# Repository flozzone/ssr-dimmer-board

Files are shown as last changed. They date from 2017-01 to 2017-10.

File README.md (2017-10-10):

# ssr-dimmer-board

Rebuild of https://github.com/fleshgordo/diskohedron using recent 
SSRs with source code for Arduino microcontroller.

## Hardware

* Schematic: https://github.com/flozzone/ssr-dimmer-board/blob/master/hw/schematic.pdf
* Layout: https://github.com/flozzone/ssr-dimmer-board/blob/master/hw/layout.pdf

## Building

    # prepare build framework
    cd src
    ./configure
    
    # building arduino v3.1 firmware
    cd bin-firmware
    make
    cd ..

    # building client library
    cd bin-client
    make
    cd ..
    
## Uploading

After having run through the building process you can upload the firmware
to the arduino. Be sure to attach the arduino with an USB cable to the 
workstation (It should be recognized as /dev/ttyUSB0).

    cd src/bin-firmware
    make upload
    
## Pin-Mapping

| Pin name 	| Description 	| Type (AVR side) 	| Arduino Pin 	| AVR Pin 	|
|---	|---	|---	|---	|---	|
| ZC 	| Zero cross 	| INPUT 	| digital pin 2 	| PD2 	|
| CH1 	| Channel1 control 	| OUTPUT 	| digital pin 4 	| PD4 	|
| CH2 	| Channel2 control 	| OUTPUT 	| digital pin 5 	| PD5 	|
| CH3 	| Channel3 control 	| OUTPUT 	| digital pin 6 	| PD6 	|
| CH4 	| Channel4 control 	| OUTPUT 	| digital pin 7 	| PD7 	|
| CH5 	| Channel5 control 	| OUTPUT 	| digital pin 8 	| PB0 	|
| GND 	| Ground 	| POWER 	| GND 	| GND 	|

## Serial Protocol

The serial protocol consists of one single 5 byte message, which is described
in the following struct message. 

For the value argument of the message, currently only values between 0 and 16
are allowed.

    struct message {
      byte magic1 = 0xF6;
      byte magic2 = 0x6F;
      enum e_fire_type fire_type;
      enum e_channels channel_nr;
      byte value;
    };

    enum e_fire_type {
        NO_FIRE,
        PHASE_TRAILING_EDGE,
        PHASE_LEADING_EDGE,
        FULL_WAVE_BURST,
        HALF_WAVE_BURST
    };

    enum e_channels {
        CHANNEL1 = 0,
        CHANNEL2,
        CHANNEL3,
        CHANNEL4,
        CHANNEL5
    };

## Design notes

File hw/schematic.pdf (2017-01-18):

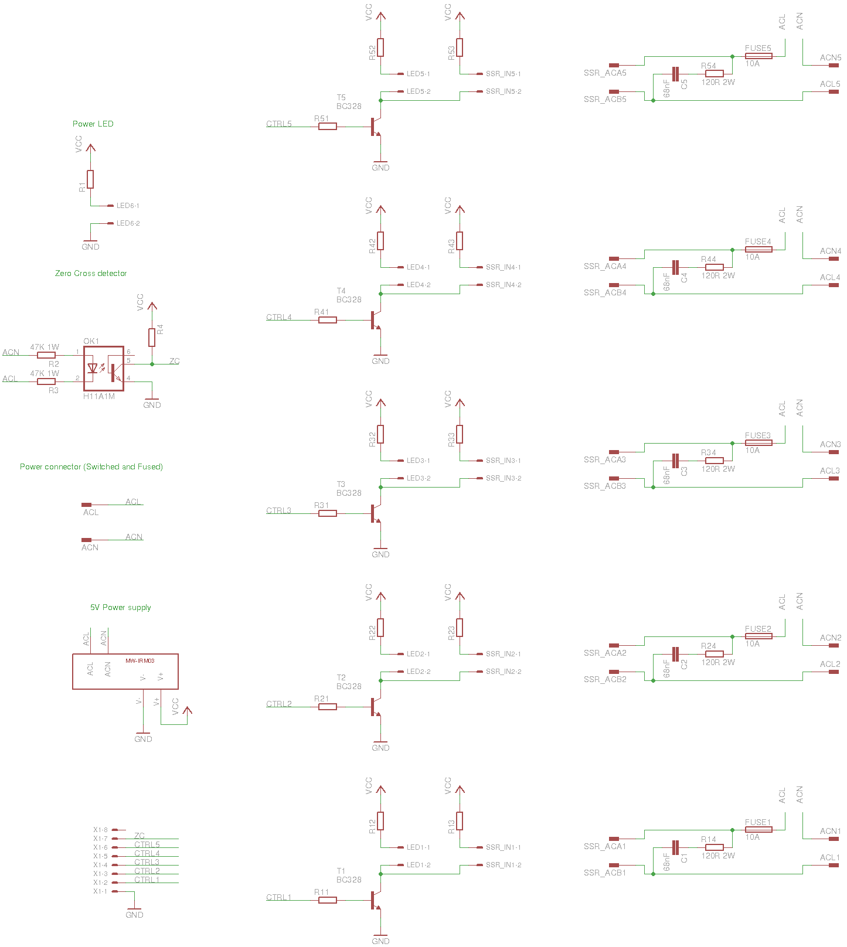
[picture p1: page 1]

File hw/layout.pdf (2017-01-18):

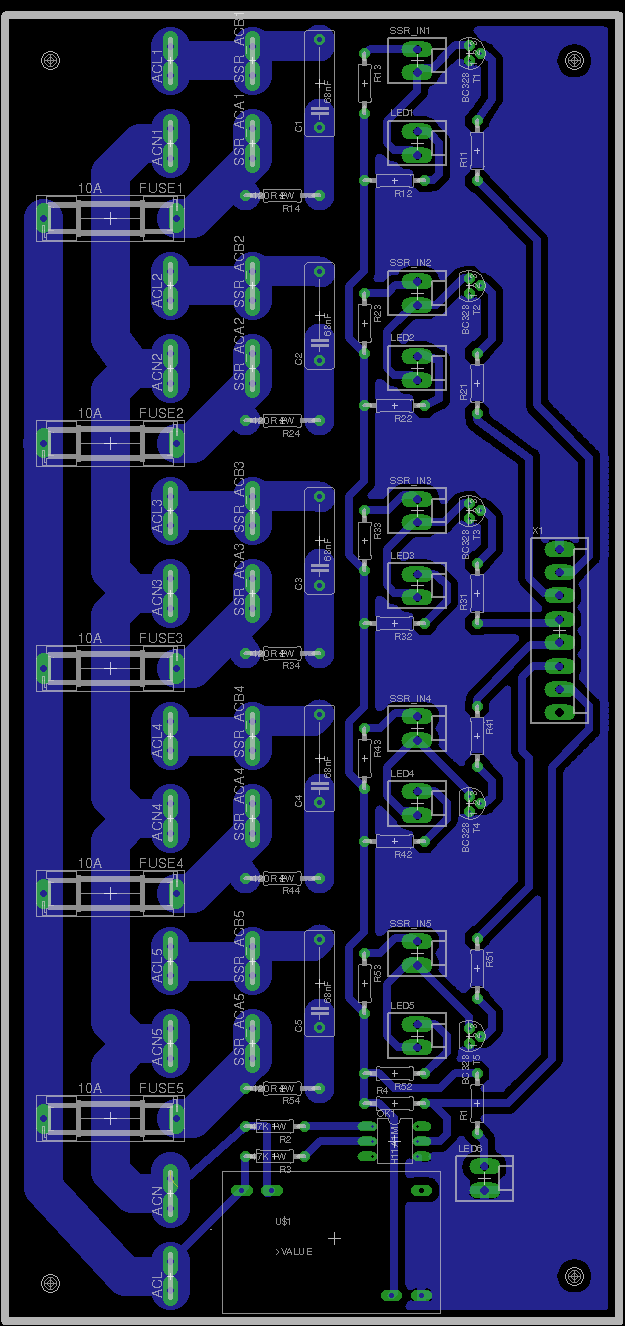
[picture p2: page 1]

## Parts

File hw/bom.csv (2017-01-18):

Part | Value | Device | Package | Description | MF | MPN | OC_FARNELL | OC_NEWARK
ACL | PIN2F061.080 | PIN2F061.080 | F061.080 | Flachstecker Typ Tyco/Electronics/AMP TAB, FASTON |  |  | unknown | unknown
ACL1 | PIN2F061.080 | PIN2F061.080 | F061.080 | Flachstecker Typ Tyco/Electronics/AMP TAB, FASTON |  |  | unknown | unknown
ACL2 | PIN2F061.080 | PIN2F061.080 | F061.080 | Flachstecker Typ Tyco/Electronics/AMP TAB, FASTON |  |  | unknown | unknown
ACL3 | PIN2F061.080 | PIN2F061.080 | F061.080 | Flachstecker Typ Tyco/Electronics/AMP TAB, FASTON |  |  | unknown | unknown
ACL4 | PIN2F061.080 | PIN2F061.080 | F061.080 | Flachstecker Typ Tyco/Electronics/AMP TAB, FASTON |  |  | unknown | unknown
ACL5 | PIN2F061.080 | PIN2F061.080 | F061.080 | Flachstecker Typ Tyco/Electronics/AMP TAB, FASTON |  |  | unknown | unknown
ACN | PIN2F061.080 | PIN2F061.080 | F061.080 | Flachstecker Typ Tyco/Electronics/AMP TAB, FASTON |  |  | unknown | unknown
ACN1 | PIN2F061.080 | PIN2F061.080 | F061.080 | Flachstecker Typ Tyco/Electronics/AMP TAB, FASTON |  |  | unknown | unknown
ACN2 | PIN2F061.080 | PIN2F061.080 | F061.080 | Flachstecker Typ Tyco/Electronics/AMP TAB, FASTON |  |  | unknown | unknown
ACN3 | PIN2F061.080 | PIN2F061.080 | F061.080 | Flachstecker Typ Tyco/Electronics/AMP TAB, FASTON |  |  | unknown | unknown
ACN4 | PIN2F061.080 | PIN2F061.080 | F061.080 | Flachstecker Typ Tyco/Electronics/AMP TAB, FASTON |  |  | unknown | unknown
ACN5 | PIN2F061.080 | PIN2F061.080 | F061.080 | Flachstecker Typ Tyco/Electronics/AMP TAB, FASTON |  |  | unknown | unknown
C1 | 100nF | C2.5/2 | C2.5-2 | CAPACITOR
C11 | 68nF | C-EU150-054X183 | C150-054X183 | CAPACITOR, European symbol
C21 | 68nF | C-EU150-054X183 | C150-054X183 | CAPACITOR, European symbol
C31 | 68nF | C-EU150-054X183 | C150-054X183 | CAPACITOR, European symbol
C41 | 68nF | C-EU150-054X183 | C150-054X183 | CAPACITOR, European symbol
C51 | 68nF | C-EU150-054X183 | C150-054X183 | CAPACITOR, European symbol
FUSE1 | 10A | FUSESH22,5 | SH22,5 | Fuse |  |  | unknown | unknown
FUSE2 | 10A | FUSESH22,5 | SH22,5 | Fuse |  |  | unknown | unknown
FUSE3 | 10A | FUSESH22,5 | SH22,5 | Fuse |  |  | unknown | unknown
FUSE4 | 10A | FUSESH22,5 | SH22,5 | Fuse |  |  | unknown | unknown
FUSE5 | 10A | FUSESH22,5 | SH22,5 | Fuse |  |  | unknown | unknown
L1 | 250uH | ATCA-08 | ATCA-08 | INDUCTOR
L2 | 250uH | ATCA-08 | ATCA-08 | INDUCTOR
L3 | 250uH | ATCA-08 | ATCA-08 | INDUCTOR
L4 | 250uH | ATCA-08 | ATCA-08 | INDUCTOR
L5 | 250uH | ATCA-08 | ATCA-08 | INDUCTOR
LED1 |  | KK-156-2 | KK-156-2 | KK 156 HEADER |  |  | unknown | unknown
LED2 |  | KK-156-2 | KK-156-2 | KK 156 HEADER |  |  | unknown | unknown
LED3 |  | KK-156-2 | KK-156-2 | KK 156 HEADER |  |  | unknown | unknown
LED4 |  | KK-156-2 | KK-156-2 | KK 156 HEADER |  |  | unknown | unknown
LED5 |  | KK-156-2 | KK-156-2 | KK 156 HEADER |  |  | unknown | unknown
LED6 |  | KK-156-2 | KK-156-2 | KK 156 HEADER |  |  | unknown | unknown
MW-IRMO3-5 | MW-IRM035 | MW-IRM035 | IRM03 | MeanWell LW-IRM03 power supply
OK1 | H11A1M | H11A1M | DIL06 | General Purpose 6-Pin Phototransistor Optocouplers |  | H11A1-M | 1021358 | 97K1793
R1 |  | R-EU_0207/10 | 0207/10 | RESISTOR, European symbol
R2 | 47K 1W | R-EU_0207/12 | 0207/12 | RESISTOR, European symbol
R3 | 47K 1W | R-EU_0207/12 | 0207/12 | RESISTOR, European symbol
R4 |  | R-EU_0207/10 | 0207/10 | RESISTOR, European symbol
R11 |  | R-EU_0207/10 | 0207/10 | RESISTOR, European symbol
R12 |  | R-EU_0207/10 | 0207/10 | RESISTOR, European symbol
R13 |  | R-EU_0207/10 | 0207/10 | RESISTOR, European symbol
R14 | 120R 2W | R-EU_0207/12 | 0207/12 | RESISTOR, European symbol
R16 |  | R-EU_0207/10 | 0207/10 | RESISTOR, European symbol
R21 |  | R-EU_0207/10 | 0207/10 | RESISTOR, European symbol
R22 |  | R-EU_0207/10 | 0207/10 | RESISTOR, European symbol
R23 |  | R-EU_0207/10 | 0207/10 | RESISTOR, European symbol
R24 | 120R 2W | R-EU_0207/12 | 0207/12 | RESISTOR, European symbol
R26 |  | R-EU_0207/10 | 0207/10 | RESISTOR, European symbol
R31 |  | R-EU_0207/10 | 0207/10 | RESISTOR, European symbol
R32 |  | R-EU_0207/10 | 0207/10 | RESISTOR, European symbol
R33 |  | R-EU_0207/10 | 0207/10 | RESISTOR, European symbol
R34 | 120R 2W | R-EU_0207/12 | 0207/12 | RESISTOR, European symbol
R36 |  | R-EU_0207/10 | 0207/10 | RESISTOR, European symbol
R41 |  | R-EU_0207/10 | 0207/10 | RESISTOR, European symbol
R42 |  | R-EU_0207/10 | 0207/10 | RESISTOR, European symbol
R43 |  | R-EU_0207/10 | 0207/10 | RESISTOR, European symbol
R44 | 120R 2W | R-EU_0207/12 | 0207/12 | RESISTOR, European symbol
R46 |  | R-EU_0207/10 | 0207/10 | RESISTOR, European symbol
R51 |  | R-EU_0207/10 | 0207/10 | RESISTOR, European symbol
R52 |  | R-EU_0207/10 | 0207/10 | RESISTOR, European symbol
R53 |  | R-EU_0207/10 | 0207/10 | RESISTOR, European symbol
R54 | 120R 2W | R-EU_0207/12 | 0207/12 | RESISTOR, European symbol
R56 |  | R-EU_0207/10 | 0207/10 | RESISTOR, European symbol
SSR_ACA1 | PIN2F061.080 | PIN2F061.080 | F061.080 | Flachstecker Typ Tyco/Electronics/AMP TAB, FASTON |  |  | unknown | unknown
SSR_ACA2 | PIN2F061.080 | PIN2F061.080 | F061.080 | Flachstecker Typ Tyco/Electronics/AMP TAB, FASTON |  |  | unknown | unknown
SSR_ACA3 | PIN2F061.080 | PIN2F061.080 | F061.080 | Flachstecker Typ Tyco/Electronics/AMP TAB, FASTON |  |  | unknown | unknown
SSR_ACA4 | PIN2F061.080 | PIN2F061.080 | F061.080 | Flachstecker Typ Tyco/Electronics/AMP TAB, FASTON |  |  | unknown | unknown
SSR_ACA5 | PIN2F061.080 | PIN2F061.080 | F061.080 | Flachstecker Typ Tyco/Electronics/AMP TAB, FASTON |  |  | unknown | unknown
SSR_ACB1 | PIN2F061.080 | PIN2F061.080 | F061.080 | Flachstecker Typ Tyco/Electronics/AMP TAB, FASTON |  |  | unknown | unknown
SSR_ACB2 | PIN2F061.080 | PIN2F061.080 | F061.080 | Flachstecker Typ Tyco/Electronics/AMP TAB, FASTON |  |  | unknown | unknown
SSR_ACB3 | PIN2F061.080 | PIN2F061.080 | F061.080 | Flachstecker Typ Tyco/Electronics/AMP TAB, FASTON |  |  | unknown | unknown
SSR_ACB4 | PIN2F061.080 | PIN2F061.080 | F061.080 | Flachstecker Typ Tyco/Electronics/AMP TAB, FASTON |  |  | unknown | unknown
SSR_ACB5 | PIN2F061.080 | PIN2F061.080 | F061.080 | Flachstecker Typ Tyco/Electronics/AMP TAB, FASTON |  |  | unknown | unknown
SSR_IN1 |  | KK-156-2 | KK-156-2 | KK 156 HEADER |  |  | unknown | unknown
SSR_IN2 |  | KK-156-2 | KK-156-2 | KK 156 HEADER |  |  | unknown | unknown
SSR_IN3 |  | KK-156-2 | KK-156-2 | KK 156 HEADER |  |  | unknown | unknown
SSR_IN4 |  | KK-156-2 | KK-156-2 | KK 156 HEADER |  |  | unknown | unknown
SSR_IN5 |  | KK-156-2 | KK-156-2 | KK 156 HEADER |  |  | unknown | unknown
T1 | BC328 | BC328 | TO92 | NPN Transistor
T2 | BC328 | BC328 | TO92 | NPN Transistor
T3 | BC328 | BC328 | TO92 | NPN Transistor
T4 | BC328 | BC328 | TO92 | NPN Transistor
T5 | BC328 | BC328 | TO92 | NPN Transistor
X1 |  | KK-156-8 | KK-156-8 | KK 156 HEADER |  |  | unknown | unknown

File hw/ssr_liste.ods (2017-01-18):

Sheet: Bauteilliste
n | Beschreibung | Shop | Bezeichnung | Link | Daten Blatt | Art. Nr. | Preis/ Artikel | Preis
1 | 19” Gehäuse | conrad | 19 Zoll Rackgehäuse 2 HE 075033 Stahl inkl. Griff | LINK (https://www.conrad.at/de/19-zoll-rackgehaeuse-2-he-075033-stahl-inkl-griff-402310.html) |  | 402310 - 6 | 36.99 | 36.99
5 | Schuko Steckdose | conrad | Anbau-Steckdose IP44 Blau PCE 105-0bw | LINK (https://www.conrad.at/de/anbau-steckdose-ip44-blau-pce-105-0bw-613469.html) | LINK (http://www.pcelectric.at/fileadmin/pce/Kataloge_PDFs/04_Schutzkontaktsteckvorrichtungen_124-157.pdf) | 613469 - 62 | 6.99 | 34.95
5 | Kabel 2,5mm² Grün/Gelb | conrad | Litze H07V-K 1 x 2.5 mm² Gelb-Grün XBK Kabel 20020101gn/ge Meterware | LINK (https://www.conrad.at/de/litze-h07v-k-1-x-25-mm-gelb-gruen-xbk-kabel-20020101gnge-meterware-1432415.html) |  | 1432415 - 62 | 0.9 | 4.5
5 | Kabel 2,5mm² Blau | conrad | Litze H07V-K 1 x 2.5 mm² Blau XBK Kabel 20020101bl Meterware | LINK (https://www.conrad.at/de/litze-h07v-k-1-x-25-mm-blau-xbk-kabel-20020101bl-meterware-1432412.html) |  | 1432412 - 62 | 0.9 | 4.5
5 | Kabel 2,5mm² Schwarz | conrad | Litze H07V-K 1 x 2.5 mm² Schwarz XBK Kabel 20020101sw Meterware | LINK (https://www.conrad.at/de/litze-h07v-k-1-x-25-mm-schwarz-xbk-kabel-20020101sw-meterware-1432410.html) |  | 1432410 - 62 | 0.9 | 4.5
3 | Kabel 2,5mm² Weiß | conrad | Litze H07V-K 1 x 2.5 mm² Weiß XBK Kabel 20020101ws Meterware | LINK (https://www.conrad.at/de/litze-h07v-k-1-x-25-mm-weiss-xbk-kabel-20020101ws-meterware-1432413.html) |  | 1432413 - 62 | 0.8 | 2.4
3 | Kabel 0.34mm² Schwarz | conrad | Litze 1 x 0.34 mm² Schwarz Kabeltronik 99220709 Meterware | LINK (https://www.conrad.at/de/litze-1-x-034-mm-schwarz-kabeltronik-99220709-meterware-323662.html) | LINK (http://www.produktinfo.conrad.com/datenblaetter/300000-324999/323662-da-01-ml-STYLE_11027_UL_LITZE__AWG_22_7__SW_de_en.pdf) | 323662 - 62 | 0.78 | 2.34
3 | Kabel 0.34mm² Orange | conrad | Litze 1 x 0.34 mm² Orange Kabeltronik 99220711 Meterware | LINK (https://www.conrad.at/de/litze-1-x-034-mm-orange-kabeltronik-99220711-meterware-323663.html) | LINK (http://www.produktinfo.conrad.com/datenblaetter/300000-324999/323663-da-01-ml-STYLE_11027_UL_LITZE__AWG_22_7__OR_de_en.pdf) | 323663 - 62 | 0.67 | 2.01
5 | SSR | mouser | Crydom CWD2425P-10 | LINK (http://www.mouser.de/ProductDetail/Crydom/CWD2425P-10/) | LINK (http://www.mouser.com/ds/2/657/c_w24-1063093.pdf) | 558-CWD2425P-10 | 45.57 | 227.85
5 | Heat Sink | mouser | Cincon M-C308 Heat Sink Kit | LINK (http://www.mouser.de/ProductDetail/Cincon/M-C308-Heat-Sink-Kit/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) | LINK (http://www.cincon.com/Product/DC_DC_Converters/List/38) | 418-MC308HEATSINKKIT | 6.32 | 31.6
5 | Heat Pad | mouser | Crydom HSP-1 | LINK (http://www.mouser.de/Search/ProductDetail.aspx?qs=PHVVF4ColZmzK%252bOYsX%2FxqQ%3D%3D) | LINK (http://www.mouser.com/ds/2/657/h_sp_1-1063408.pdf) | 558-HSP-1 | 0.968 | 4.84
1 | Kaltgeräte Dose | mouser | Delta Electronics 20GEEG3E | LINK (http://www.mouser.de/ProductDetail/Delta-Electronics/20GEEG3E/) | LINK (http://www.mouser.com/ds/2/632/GE-515687.pdf) | 108-20GEEG3E | 11.12 | 11.12
1 | 5V Netzteil | mouser | Mean Well IRM-03-5 | LINK (http://www.mouser.de/ProductDetail/Mean-Well/IRM-03-5/) | LINK (http://www.mouser.com/ds/2/260/IRM-03-spec-881203.pdf) | 709-IRM03-5 | 7.34 | 7.34
10 | LED für Gehäuse mit Kabel | mouser | Dialight 558-0201-007F | LINK (http://www.mouser.de/ProductDetail/Dialight/558-0201-007F/?qs=sGAEpiMZZMsUguuR3b6UZjrITrX0AWF02rgFPgPbD0A%3D) | LINK (http://www.mouser.com/ds/2/109/558-0x01-00x-186133.pdf) | 645-558-0201-007F | 1.3 | 13
10 | Sockel (2 pin) | mouser | Molex 22-23-2021 | LINK (http://www.mouser.de/ProductDetail/Molex/22-23-2021/) | LINK (http://www.mouser.com/ds/2/276/0022232021_PCB_HEADERS-526518.pdf) | 538-22-23-2021 | 0.098 | 0.98
10 | Stecker (2 pin) | mouser | Molex 22-01-2025 | LINK (http://www.mouser.de/Search/ProductDetail.aspx?qs=mrPiglD9aYKHxZkM06vJ3A%3D%3D) | LINK (http://www.mouser.com/ds/2/276/0022012025_CRIMP_HOUSINGS-158205.pdf) | 538-22-01-2025 | 0.179 | 1.79
30 | Kontakte | mouser | Molex 08-50-0032 | LINK (http://www.mouser.de/ProductDetail/Molex/08-50-0032/) | LINK (http://www.mouser.com/ds/2/276/0008500032_CRIMP_TERMINALS-156108.pdf) | 538-08-50-0032 | 0.088 | 2.64
3 | Sockel (8 pin) | mouser | Molex 22-27-2081 | LINK (http://www.mouser.de/ProductDetail/Molex/22-27-2081/) | LINK (http://www.mouser.com/ds/2/276/0022272081_PCB_HEADERS-526526.pdf) | 538-22-27-2081 | 0.519 | 1.557
3 | Stecker (8 pin) | mouser | Molex 22-01-2025 | LINK (http://www.mouser.de/Search/ProductDetail.aspx?qs=mrPiglD9aYKHxZkM06vJ3A%3D%3D) | LINK (http://www.mouser.com/ds/2/276/0022012025_CRIMP_HOUSINGS-158205.pdf) | 538-22-01-2025 | 0.236 | 0.708
3 | Stecker (40 pin) arduino | mouser | Molex 90120-0160 | LINK (http://www.mouser.de/ProductDetail/Molex/90120-0160/) | LINK (http://www.mouser.com/ds/2/276/0901200160_PCB_HEADERS-230112.pdf) | 538-90120-0160 | 2.4 | 7.2
6 | Sockel (15 pin) arduino | mouser | Molex 90147-1115 | LINK (http://www.mouser.de/ProductDetail/Molex/90147-1115/) | LINK (http://www.mouser.com/ds/2/276/901471102_sd-339177.pdf) | 538-90147-1115 | 2.9 | 17.4
1 | Hauptschalter | mouser | C&K Components DF52J12S215PQA | LINK (http://www.mouser.de/ProductDetail/CK-Components/DF52J12S215PQA/) | LINK (http://www.mouser.com/ds/2/60/df-965355.pdf) | 611-DF52J12S215PQA | 4.68 | 4.68
25 | 230V Kontakte (male) | mouser | TE Connectivity / AMP 1217136-1 | LINK (http://www.mouser.de/ProductDetail/TE-Connectivity-AMP/1217136-1/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) | LINK (http://www.mouser.com/ds/2/418/NG_CD_1217136_G1-646370.pdf) | 571-1217136-1 | 0.114 | 2.85
40 | 230V Kontakte (female) | mouser | TE Connectivity / AMP 3-520408-2 | LINK (http://www.mouser.de/ProductDetail/TE-Connectivity-AMP/3-520408-2/) | LINK (http://www.mouser.com/ds/2/418/NG_CD_520408_K_baseFilename-761123.pdf) | 571-35204082 | 0.329 | 13.16
1 | Hauptsicherungshalter | mouser | Littelfuse 03455LS7H | LINK (http://www.mouser.de/ProductDetail/Littelfuse/03455LS7H/) | LINK (http://www.mouser.com/ds/2/240/Littelfuse_Fuse_Holder_345_Panel_Mount_Datasheet.p-46486.pdf) | 576-03455LS7H | 3.48 | 3.48
1 | Sicherungshalter 10A | mouser | Schurter 0031.8201 | LINK (http://www.mouser.de/ProductDetail/Schurter/00318201/?qs=sGAEpiMZZMuxTAA0eeO5Gw59anVqG7J0yLU8NKrpOQg%3D) | LINK (http://www.mouser.com/ds/2/358/typ_OGN-14523.pdf) | 693-0031.8201 | 0.56 | 0.56
7 | Sicherung 10A | mouser | Littelfuse 0216010.MXEP | LINK (http://www.mouser.de/ProductDetail/Littelfuse/0216010MXEP/) | LINK (http://www.mouser.com/ds/2/240/216P-13338.pdf) | 576-0216010.MXEP | 1.77 | 12.39
2 | Sicherung 16A | mouser | Littelfuse 0216016.MXP | LINK (http://www.mouser.de/ProductDetail/Littelfuse/0216016MXP/?qs=sGAEpiMZZMsIz3CjQ1xegfV9hnZiCDpKIuunlDXx2Rw%3D) | LINK (http://www.mouser.com/ds/2/240/216P-13338.pdf) | 576-0216016.MXP | 1.32 | 2.64
7 | Widerstand 2W 120R | mouser | Ohmite OY121KE | LINK (http://www.mouser.de/ProductDetail/Ohmite/OY121KE/) | LINK (http://www.mouser.com/ds/2/303/ox_oy_series-24882.pdf) | 588-OY-120-E | 1.66 | 11.62
4 | Widerstand 1W 47K | mouser | Ohmite OY473KE | LINK (http://www.mouser.com/ds/2/303/ox_oy_series-24882.pdf) | LINK (http://www.mouser.com/ds/2/303/ox_oy_series-24882.pdf) | 588-OY-47K-E | 1.66 | 6.64
10 | Kondensator 68nF | mouser | EPCOS / TDK B32922C3683K189 | LINK (http://www.mouser.de/ProductDetail/EPCOS-TDK/B32922C3683K189/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) | LINK (http://www.mouser.com/ds/2/400/X2_B32921_928-1061769.pdf) | 871-B32922C3683K189 | 0.732 | 7.32
3 | Optokoppler für Zero Cross | mouser | Fairchild Semiconductor H11A1M | LINK (http://www.mouser.de/ProductDetail/Fairchild-Semiconductor/H11A1M/) | LINK (http://www.mouser.com/ds/2/149/H11A1M-889190.pdf) | 512-H11A1M | 0.503 | 1.509
5 | Ringkerndrossel | mouser | ABRACON ATCA-08-251M-V | LINK (http://www.mouser.de/ProductDetail/ABRACON/ATCA-08-251M-V/) | LINK (http://www.mouser.com/ds/2/3/ATCASeries-963802.pdf) | 815-ATCA-08-251M-V | 9.02 | 45.1
5 | Arduino Nano | mouser | Arduino ARD-NANO30NP | LINK (http://www.mouser.de/ProductDetail/Arduino/ARD-NANO30NP/) | LINK (http://www.mouser.com/ds/2/595/Arduino_Nano3_0-220057.pdf) | 992-ARD-NANO30NP | 29.03 | 145.15
10 | Entstörkondensator | mouser | Vishay / BC Components K104K15X7RF53L2 | LINK (http://www.mouser.de/ProductDetail/Vishay-BC-Components/K104K15X7RF53L2/) | LINK (http://www.mouser.com/ds/2/427/mkseries-205465.pdf) | 594-K104K15X7RF53L2 | 0.094 | 0.94
10 | Transistor | mouser | Fairchild Semiconductor BC547B | LINK (http://www.mouser.de/ProductDetail/Fairchild-Semiconductor/BC547B/) | LINK (http://www.mouser.com/ds/2/149/BC547-888524.pdf) | 512-BC547B | 0.211 | 2.11
 |  |  |  |  |  |  | Total | 678.254

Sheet: Bauteilliste2
n | Beschreibung | Shop | Bezeichnung | Link | Daten Blatt | Art. Nr. | Preis/ Artikel | Preis
5 | Sicherungshalter 10A | mouser | Schurter 0031.8201 | LINK (http://www.mouser.de/ProductDetail/Schurter/00318201/?qs=sGAEpiMZZMuxTAA0eeO5Gw59anVqG7J0yLU8NKrpOQg%3D) | LINK (http://www.mouser.com/ds/2/358/typ_OGN-14523.pdf) | 693-0031.8201 | 0.56 | 2.8
1 | Hauptschalter | mouser | CW Industries GRS-4022-0013 | LINK (http://www.mouser.de/ProductDetail/CW-Industries/GRS-4022-0013/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) | LINK (http://www.mouser.com/ds/2/97/GRS-4022-0013-784663.pdf) | 629-GRS402213 | 1.46 | 1.46
 |  |  |  |  |  |  | Total | 4.26

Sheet: bom
Part | Value | Device | Package | Description | MF | MPN | OC_FARNELL | OC_NEWARK
ACL | PIN2F061.080 | PIN2F061.080 | F061.080 | Flachstecker Typ Tyco/Electronics/AMP TAB, FASTON |  |  | unknown | unknown
ACL1 | PIN2F061.080 | PIN2F061.080 | F061.080 | Flachstecker Typ Tyco/Electronics/AMP TAB, FASTON |  |  | unknown | unknown
ACL2 | PIN2F061.080 | PIN2F061.080 | F061.080 | Flachstecker Typ Tyco/Electronics/AMP TAB, FASTON |  |  | unknown | unknown
ACL3 | PIN2F061.080 | PIN2F061.080 | F061.080 | Flachstecker Typ Tyco/Electronics/AMP TAB, FASTON |  |  | unknown | unknown
ACL4 | PIN2F061.080 | PIN2F061.080 | F061.080 | Flachstecker Typ Tyco/Electronics/AMP TAB, FASTON |  |  | unknown | unknown
ACL5 | PIN2F061.080 | PIN2F061.080 | F061.080 | Flachstecker Typ Tyco/Electronics/AMP TAB, FASTON |  |  | unknown | unknown
ACN | PIN2F061.080 | PIN2F061.080 | F061.080 | Flachstecker Typ Tyco/Electronics/AMP TAB, FASTON |  |  | unknown | unknown
ACN1 | PIN2F061.080 | PIN2F061.080 | F061.080 | Flachstecker Typ Tyco/Electronics/AMP TAB, FASTON |  |  | unknown | unknown
ACN2 | PIN2F061.080 | PIN2F061.080 | F061.080 | Flachstecker Typ Tyco/Electronics/AMP TAB, FASTON |  |  | unknown | unknown
ACN3 | PIN2F061.080 | PIN2F061.080 | F061.080 | Flachstecker Typ Tyco/Electronics/AMP TAB, FASTON |  |  | unknown | unknown
ACN4 | PIN2F061.080 | PIN2F061.080 | F061.080 | Flachstecker Typ Tyco/Electronics/AMP TAB, FASTON |  |  | unknown | unknown
ACN5 | PIN2F061.080 | PIN2F061.080 | F061.080 | Flachstecker Typ Tyco/Electronics/AMP TAB, FASTON |  |  | unknown | unknown
C1 | 100nF | C2.5/2 | C2.5-2 | CAPACITOR
C11 | 68nF | C-EU150-054X183 | C150-054X183 | CAPACITOR, European symbol
C21 | 68nF | C-EU150-054X183 | C150-054X183 | CAPACITOR, European symbol
C31 | 68nF | C-EU150-054X183 | C150-054X183 | CAPACITOR, European symbol
C41 | 68nF | C-EU150-054X183 | C150-054X183 | CAPACITOR, European symbol
C51 | 68nF | C-EU150-054X183 | C150-054X183 | CAPACITOR, European symbol
FUSE1 | 10A | FUSESH22,5 | SH22,5 | Fuse |  |  | unknown | unknown
FUSE2 | 10A | FUSESH22,5 | SH22,5 | Fuse |  |  | unknown | unknown
FUSE3 | 10A | FUSESH22,5 | SH22,5 | Fuse |  |  | unknown | unknown
FUSE4 | 10A | FUSESH22,5 | SH22,5 | Fuse |  |  | unknown | unknown
FUSE5 | 10A | FUSESH22,5 | SH22,5 | Fuse |  |  | unknown | unknown
L1 | 250uH | ATCA-08 | ATCA-08 | INDUCTOR
L2 | 250uH | ATCA-08 | ATCA-08 | INDUCTOR
L3 | 250uH | ATCA-08 | ATCA-08 | INDUCTOR
L4 | 250uH | ATCA-08 | ATCA-08 | INDUCTOR
L5 | 250uH | ATCA-08 | ATCA-08 | INDUCTOR
LED1 |  | KK-156-2 | KK-156-2 | KK 156 HEADER |  |  | unknown | unknown
LED2 |  | KK-156-2 | KK-156-2 | KK 156 HEADER |  |  | unknown | unknown
LED3 |  | KK-156-2 | KK-156-2 | KK 156 HEADER |  |  | unknown | unknown
LED4 |  | KK-156-2 | KK-156-2 | KK 156 HEADER |  |  | unknown | unknown
LED5 |  | KK-156-2 | KK-156-2 | KK 156 HEADER |  |  | unknown | unknown
LED6 |  | KK-156-2 | KK-156-2 | KK 156 HEADER |  |  | unknown | unknown
MW-IRMO3-5 | MW-IRM035 | MW-IRM035 | IRM03 | MeanWell LW-IRM03 power supply
OK1 | H11A1M | H11A1M | DIL06 | General Purpose 6-Pin Phototransistor Optocouplers |  | H11A1-M | 1021358 | 97K1793
R1 |  | R-EU_0207/10 | 0207/10 | RESISTOR, European symbol
R2 | 47K 1W | R-EU_0207/12 | 0207/12 | RESISTOR, European symbol
R3 | 47K 1W | R-EU_0207/12 | 0207/12 | RESISTOR, European symbol
R4 |  | R-EU_0207/10 | 0207/10 | RESISTOR, European symbol
R11 |  | R-EU_0207/10 | 0207/10 | RESISTOR, European symbol
R12 |  | R-EU_0207/10 | 0207/10 | RESISTOR, European symbol
R13 |  | R-EU_0207/10 | 0207/10 | RESISTOR, European symbol
R14 | 120R 2W | R-EU_0207/12 | 0207/12 | RESISTOR, European symbol
R16 |  | R-EU_0207/10 | 0207/10 | RESISTOR, European symbol
R21 |  | R-EU_0207/10 | 0207/10 | RESISTOR, European symbol
R22 |  | R-EU_0207/10 | 0207/10 | RESISTOR, European symbol
R23 |  | R-EU_0207/10 | 0207/10 | RESISTOR, European symbol
R24 | 120R 2W | R-EU_0207/12 | 0207/12 | RESISTOR, European symbol
R26 |  | R-EU_0207/10 | 0207/10 | RESISTOR, European symbol
R31 |  | R-EU_0207/10 | 0207/10 | RESISTOR, European symbol
R32 |  | R-EU_0207/10 | 0207/10 | RESISTOR, European symbol
R33 |  | R-EU_0207/10 | 0207/10 | RESISTOR, European symbol
R34 | 120R 2W | R-EU_0207/12 | 0207/12 | RESISTOR, European symbol
R36 |  | R-EU_0207/10 | 0207/10 | RESISTOR, European symbol
R41 |  | R-EU_0207/10 | 0207/10 | RESISTOR, European symbol
R42 |  | R-EU_0207/10 | 0207/10 | RESISTOR, European symbol
R43 |  | R-EU_0207/10 | 0207/10 | RESISTOR, European symbol
R44 | 120R 2W | R-EU_0207/12 | 0207/12 | RESISTOR, European symbol
R46 |  | R-EU_0207/10 | 0207/10 | RESISTOR, European symbol
R51 |  | R-EU_0207/10 | 0207/10 | RESISTOR, European symbol
R52 |  | R-EU_0207/10 | 0207/10 | RESISTOR, European symbol
R53 |  | R-EU_0207/10 | 0207/10 | RESISTOR, European symbol
R54 | 120R 2W | R-EU_0207/12 | 0207/12 | RESISTOR, European symbol
R56 |  | R-EU_0207/10 | 0207/10 | RESISTOR, European symbol
SSR_ACA1 | PIN2F061.080 | PIN2F061.080 | F061.080 | Flachstecker Typ Tyco/Electronics/AMP TAB, FASTON |  |  | unknown | unknown
SSR_ACA2 | PIN2F061.080 | PIN2F061.080 | F061.080 | Flachstecker Typ Tyco/Electronics/AMP TAB, FASTON |  |  | unknown | unknown
SSR_ACA3 | PIN2F061.080 | PIN2F061.080 | F061.080 | Flachstecker Typ Tyco/Electronics/AMP TAB, FASTON |  |  | unknown | unknown
SSR_ACA4 | PIN2F061.080 | PIN2F061.080 | F061.080 | Flachstecker Typ Tyco/Electronics/AMP TAB, FASTON |  |  | unknown | unknown
SSR_ACA5 | PIN2F061.080 | PIN2F061.080 | F061.080 | Flachstecker Typ Tyco/Electronics/AMP TAB, FASTON |  |  | unknown | unknown
SSR_ACB1 | PIN2F061.080 | PIN2F061.080 | F061.080 | Flachstecker Typ Tyco/Electronics/AMP TAB, FASTON |  |  | unknown | unknown
SSR_ACB2 | PIN2F061.080 | PIN2F061.080 | F061.080 | Flachstecker Typ Tyco/Electronics/AMP TAB, FASTON |  |  | unknown | unknown
SSR_ACB3 | PIN2F061.080 | PIN2F061.080 | F061.080 | Flachstecker Typ Tyco/Electronics/AMP TAB, FASTON |  |  | unknown | unknown
SSR_ACB4 | PIN2F061.080 | PIN2F061.080 | F061.080 | Flachstecker Typ Tyco/Electronics/AMP TAB, FASTON |  |  | unknown | unknown
SSR_ACB5 | PIN2F061.080 | PIN2F061.080 | F061.080 | Flachstecker Typ Tyco/Electronics/AMP TAB, FASTON |  |  | unknown | unknown
SSR_IN1 |  | KK-156-2 | KK-156-2 | KK 156 HEADER |  |  | unknown | unknown
SSR_IN2 |  | KK-156-2 | KK-156-2 | KK 156 HEADER |  |  | unknown | unknown
SSR_IN3 |  | KK-156-2 | KK-156-2 | KK 156 HEADER |  |  | unknown | unknown
SSR_IN4 |  | KK-156-2 | KK-156-2 | KK 156 HEADER |  |  | unknown | unknown
SSR_IN5 |  | KK-156-2 | KK-156-2 | KK 156 HEADER |  |  | unknown | unknown
T1 | BC328 | BC328 | TO92 | NPN Transistor
T2 | BC328 | BC328 | TO92 | NPN Transistor
T3 | BC328 | BC328 | TO92 | NPN Transistor
T4 | BC328 | BC328 | TO92 | NPN Transistor
T5 | BC328 | BC328 | TO92 | NPN Transistor
X1 |  | KK-156-8 | KK-156-8 | KK 156 HEADER |  |  | unknown | unknown

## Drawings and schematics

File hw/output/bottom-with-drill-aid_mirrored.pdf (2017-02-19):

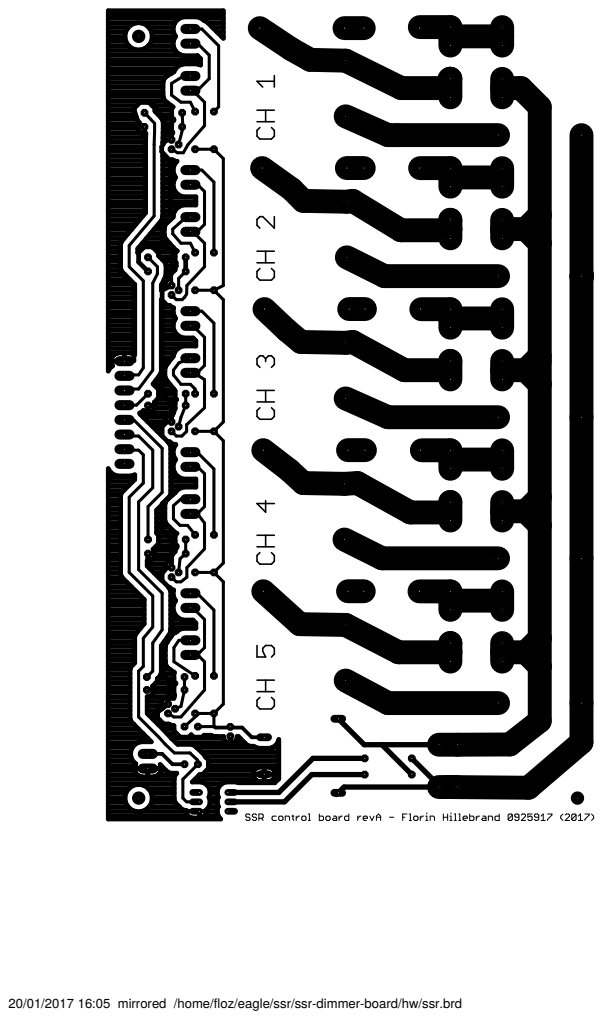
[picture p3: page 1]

20/01/2017 16:05 mirrored /home/floz/eagle/ssr/ssr-dimmer-board/hw/ssr.brd

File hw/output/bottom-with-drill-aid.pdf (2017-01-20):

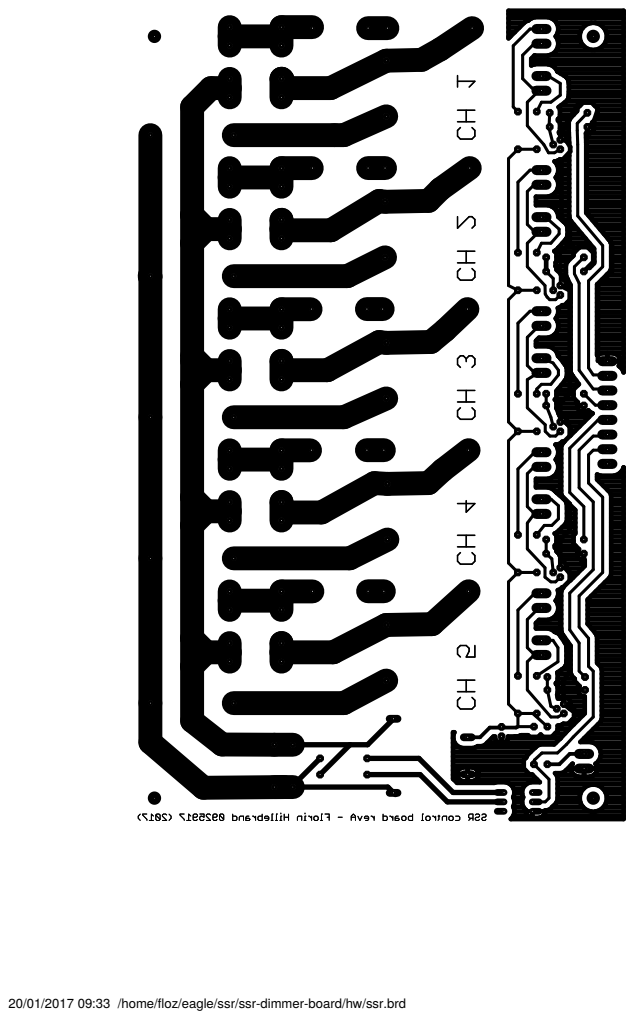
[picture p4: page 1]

20/01/2017 09:33 /home/floz/eagle/ssr/ssr-dimmer-board/hw/ssr.brd

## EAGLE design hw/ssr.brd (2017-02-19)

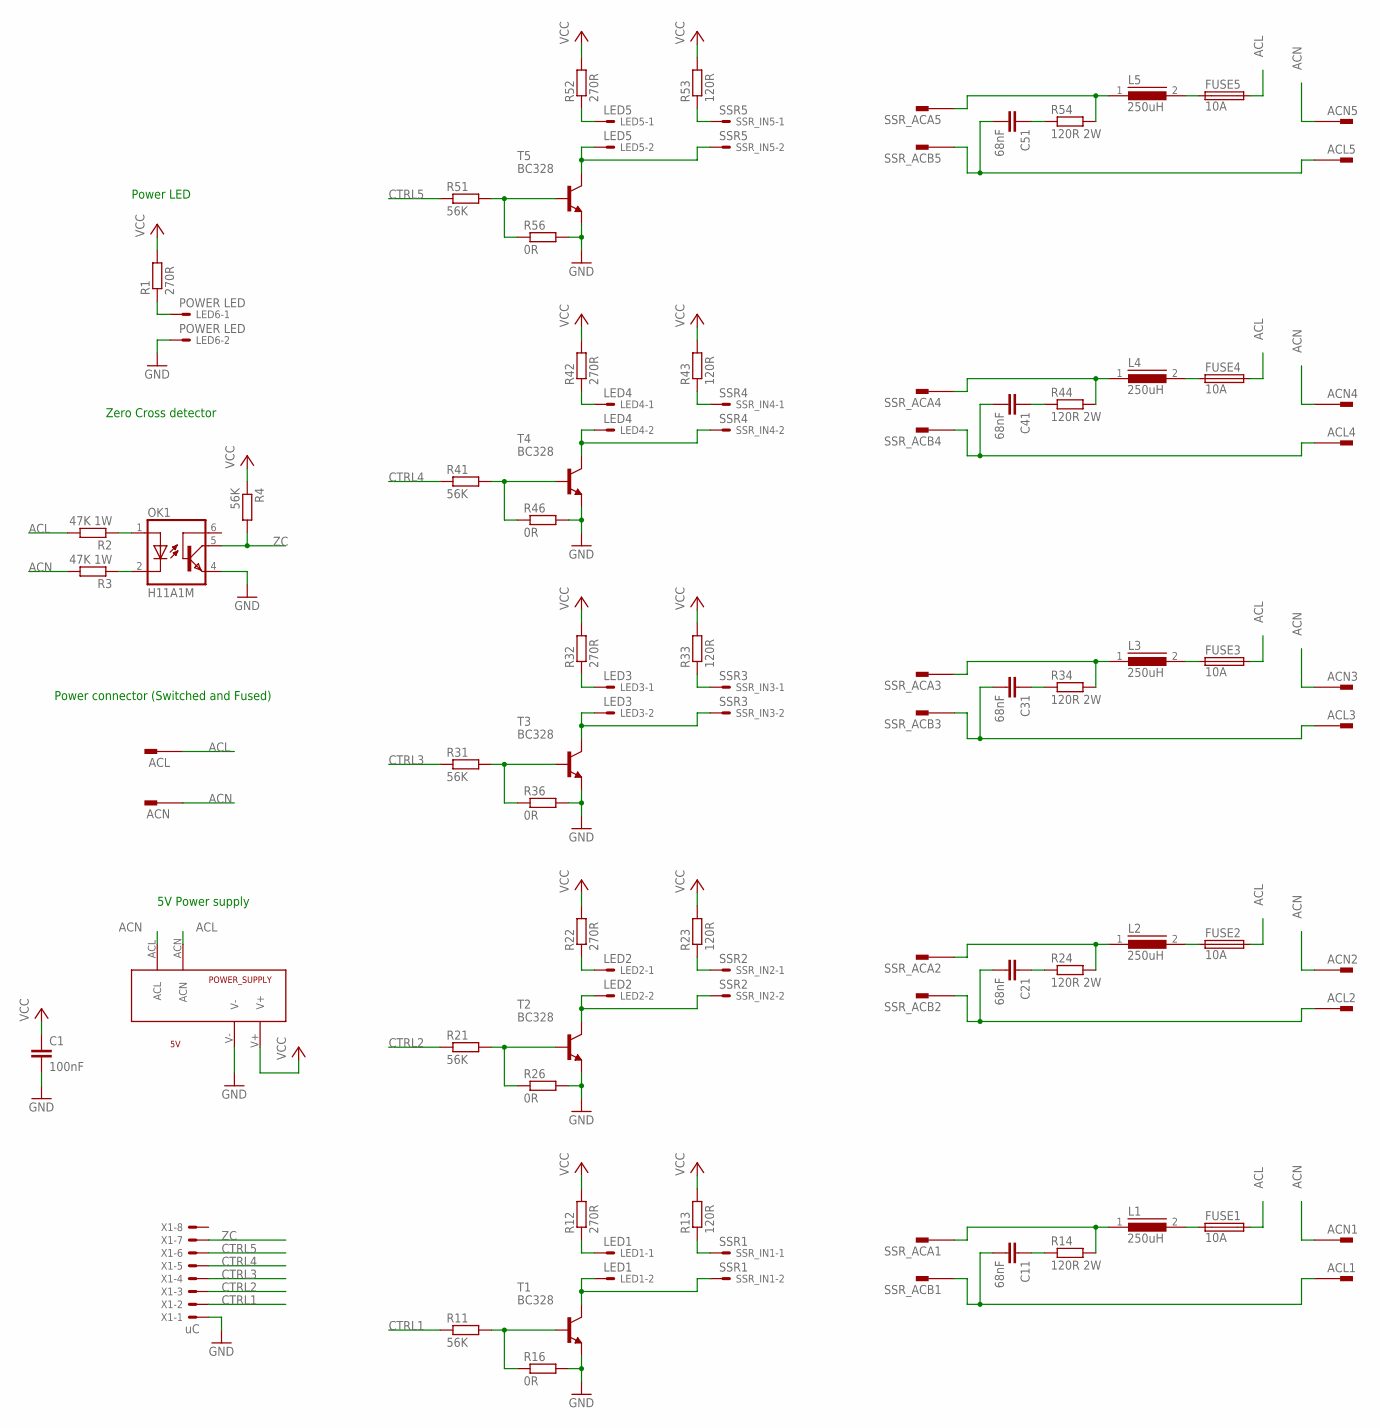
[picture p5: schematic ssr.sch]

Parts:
ACL, ACL1, ACL2, ACL3, ACL4, ACL5: PIN2F061.080; F061.080
ACN, ACN1, ACN2, ACN3, ACN4, ACN5: PIN2F061.080; F061.080
C1: 100nF; C2.5-2
C11, C21, C31, C41, C51: 68nF; C150-054X183
FUSE1, FUSE2, FUSE3, FUSE4, FUSE5: 10A; SH22,5
L1, L2, L3, L4, L5: 250uH; ATCA-08
LED1: LED1; KK-156-2
LED2: LED2; KK-156-2
LED3: LED3; KK-156-2
LED4: LED4; KK-156-2
LED5: LED5; KK-156-2
LED6: POWER LED; KK-156-2
OK1: H11A1M; DIL06
POWER_SUPPLY: 5V; SPN00205
R1, R12, R22, R32, R42, R52: 270R; 0207/10
R2, R3: 47K 1W; 0309/12
R4, R11, R21, R31, R41, R51: 56K; 0207/10
R13, R23, R33, R43, R53: 120R; 0207/10
R14, R24, R34, R44, R54: 120R 2W; 0617/22
R16, R26, R36, R46, R56: 0R; 0207/10
SSR_ACA1, SSR_ACA2, SSR_ACA3, SSR_ACA4, SSR_ACA5: PIN2F061.080; F061.080
SSR_ACB1, SSR_ACB2, SSR_ACB3, SSR_ACB4, SSR_ACB5: PIN2F061.080; F061.080
SSR_IN1: SSR1; KK-156-2
SSR_IN2: SSR2; KK-156-2
SSR_IN3: SSR3; KK-156-2
SSR_IN4: SSR4; KK-156-2
SSR_IN5: SSR5; KK-156-2
T1, T2, T3, T4, T5: BC328; TO92
X1: uC; KK-156-8

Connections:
ACL: ACL.1A, ACL.1B, FUSE1.2, FUSE2.2, FUSE3.2, FUSE4.2, FUSE5.2, POWER_SUPPLY.ACN, R2.2
ACN: ACN.1A, ACN.1B, ACN1.1A, ACN1.1B, ACN2.1A, ACN2.1B, ACN3.1A, ACN3.1B, ACN4.1A, ACN4.1B, ACN5.1A, ACN5.1B, POWER_SUPPLY.ACL, R3.2
CTRL1: R11.1, X1.2
CTRL2: R21.1, X1.3
CTRL3: R31.1, X1.4
CTRL4: R41.1, X1.5
CTRL5: R51.1, X1.6
GND: C1.2, LED6.2, OK1.4 (EMI), POWER_SUPPLY.V-, R16.2, R26.2, R36.2, R46.2, R56.2, T1.1 (E), T2.1 (E), T3.1 (E), T4.1 (E), T5.1 (E), X1.1
unnamed: LED1.2, SSR_IN1.2, T1.3 (C)
unnamed: LED1.1, R12.1
unnamed: R13.1, SSR_IN1.1
unnamed: R11.2, R16.1, T1.2 (B)
unnamed: C11.1, R14.1
unnamed: OK1.2 (C), R3.1
unnamed: OK1.1 (A), R2.1
unnamed: R23.1, SSR_IN2.1
unnamed: LED2.1, R22.1
unnamed: R21.2, R26.1, T2.2 (B)
unnamed: C21.1, R24.1
unnamed: LED2.2, SSR_IN2.2, T2.3 (C)
unnamed: R33.1, SSR_IN3.1
unnamed: LED3.1, R32.1
unnamed: R31.2, R36.1, T3.2 (B)
unnamed: C31.1, R34.1
unnamed: LED3.2, SSR_IN3.2, T3.3 (C)
unnamed: R43.1, SSR_IN4.1
unnamed: LED4.1, R42.1
unnamed: R41.2, R46.1, T4.2 (B)
unnamed: C41.1, R44.1
unnamed: LED4.2, SSR_IN4.2, T4.3 (C)
unnamed: R53.1, SSR_IN5.1
unnamed: LED5.1, R52.1
unnamed: R51.2, R56.1, T5.2 (B)
unnamed: C51.1, R54.1
unnamed: LED5.2, SSR_IN5.2, T5.3 (C)
unnamed: LED6.1, R1.1
unnamed: FUSE5.1, L5.2
unnamed: FUSE4.1, L4.2
unnamed: FUSE3.1, L3.2
unnamed: FUSE2.1, L2.2
unnamed: FUSE1.1, L1.2
SSR_ACA1: L1.1, R14.2, SSR_ACA1.1A, SSR_ACA1.1B
SSR_ACA2: L2.1, R24.2, SSR_ACA2.1A, SSR_ACA2.1B
SSR_ACA3: L3.1, R34.2, SSR_ACA3.1A, SSR_ACA3.1B
SSR_ACA4: L4.1, R44.2, SSR_ACA4.1A, SSR_ACA4.1B
SSR_ACA5: L5.1, R54.2, SSR_ACA5.1A, SSR_ACA5.1B
SSR_ACB1: ACL1.1A, ACL1.1B, C11.2, SSR_ACB1.1A, SSR_ACB1.1B
SSR_ACB2: ACL2.1A, ACL2.1B, C21.2, SSR_ACB2.1A, SSR_ACB2.1B
SSR_ACB3: ACL3.1A, ACL3.1B, C31.2, SSR_ACB3.1A, SSR_ACB3.1B
SSR_ACB4: ACL4.1A, ACL4.1B, C41.2, SSR_ACB4.1A, SSR_ACB4.1B
SSR_ACB5: ACL5.1A, ACL5.1B, C51.2, SSR_ACB5.1A, SSR_ACB5.1B
VCC: C1.1, POWER_SUPPLY.V+, R1.2, R4.1, R12.2, R13.2, R22.2, R23.2, R32.2, R33.2, R42.2, R43.2, R52.2, R53.2
ZC: OK1.5 (COL), R4.2, X1.7

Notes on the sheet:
Power connector (Switched and Fused)
5V Power supply
Zero Cross detector
Power LED

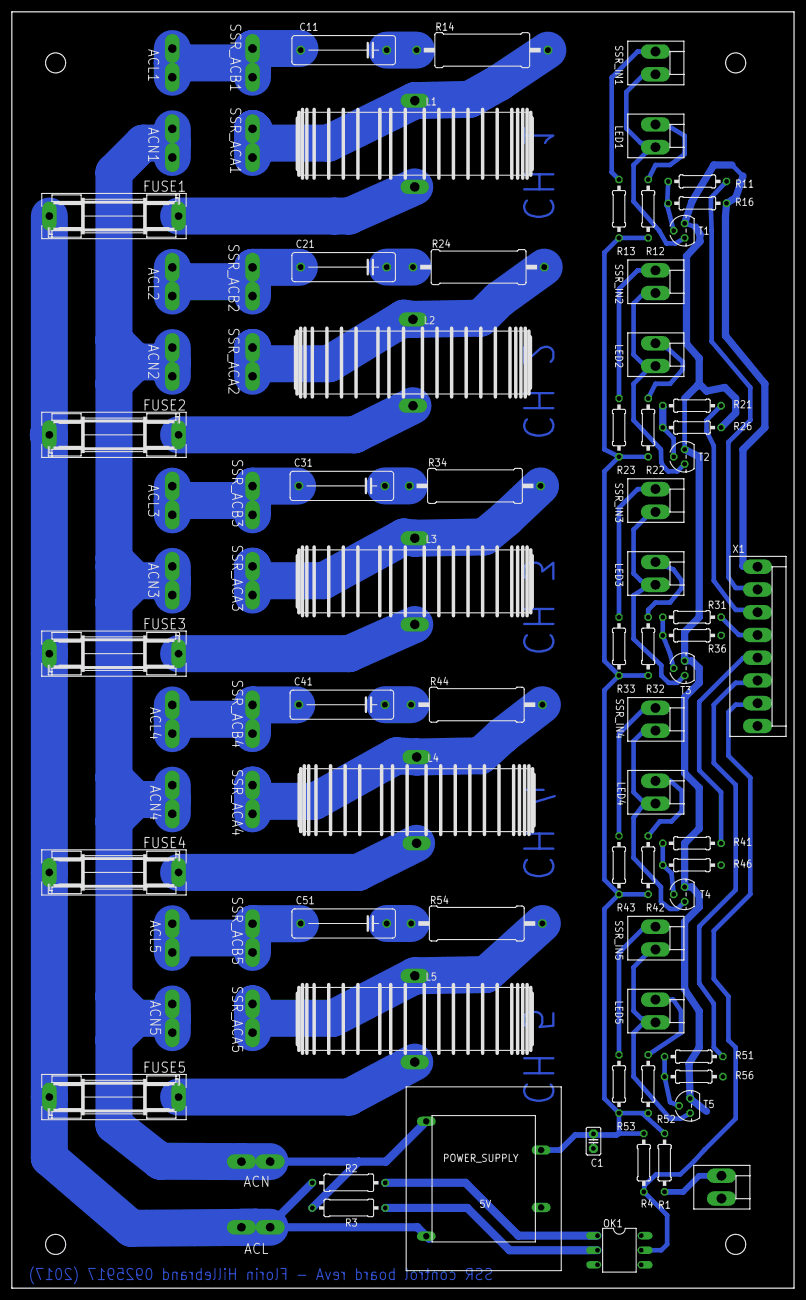
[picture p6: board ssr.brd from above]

Board: 2 copper layers, 136.2 x 222.2 mm, 87 parts (0 on the bottom side), 53 nets.

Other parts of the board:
DRILEGEND: DRILEGEND

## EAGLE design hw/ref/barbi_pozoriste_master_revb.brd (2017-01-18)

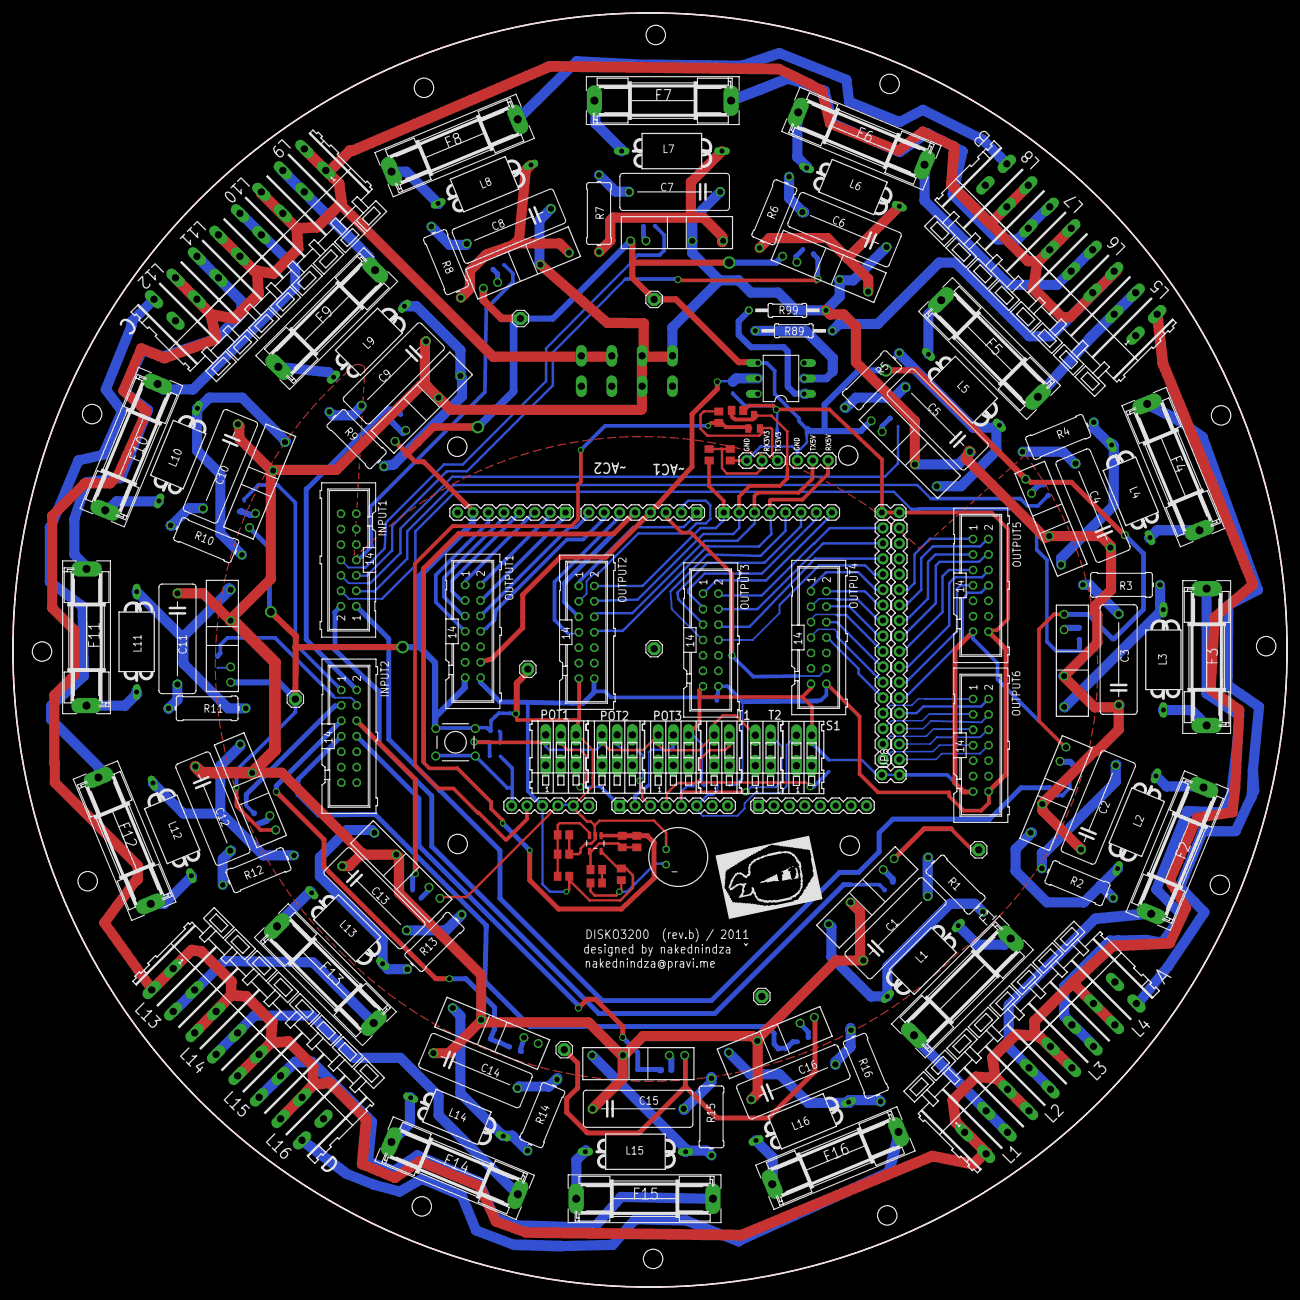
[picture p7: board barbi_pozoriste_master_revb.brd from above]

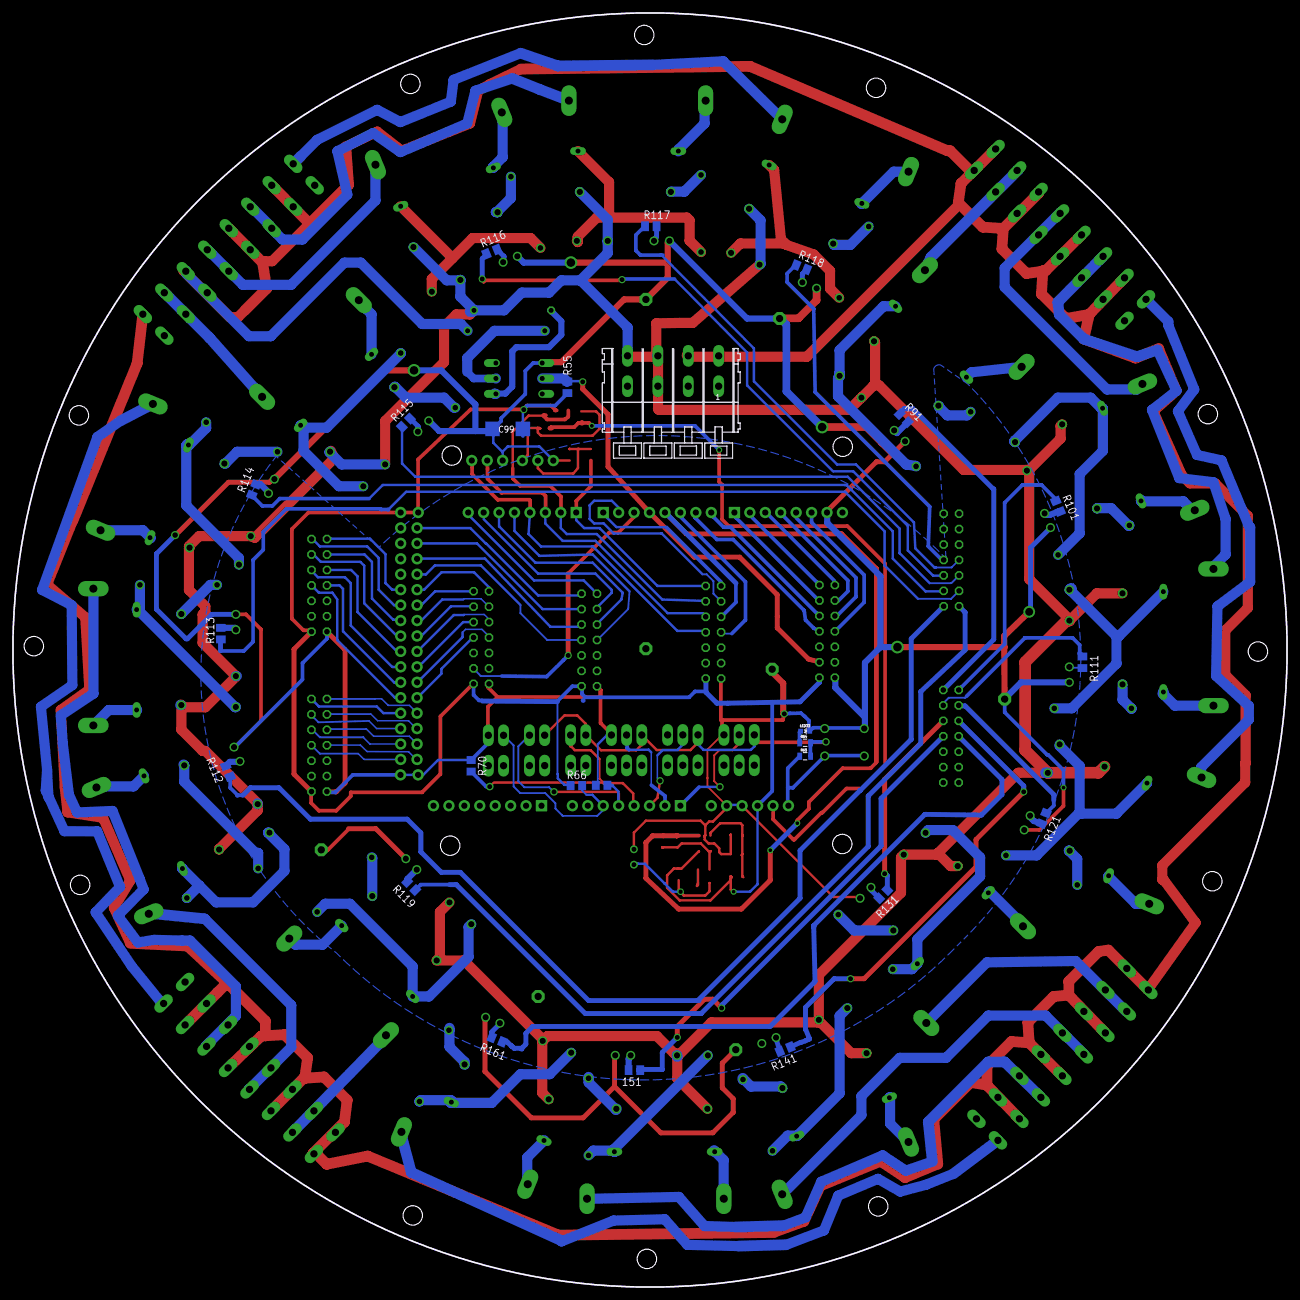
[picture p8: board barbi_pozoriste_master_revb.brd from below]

Board: 2 copper layers, 209.7 x 209.7 mm, 162 parts (25 on the bottom side), 168 nets.

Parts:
151: 330R; M0805
C1, C2, C3, C4, C5, C6, C7, C8, C9, C10, C11, C12, C13, C14, C15, C16: 68nF; C150-064X183
C17: 4.7uF; C0805
C18: 12pF; C0805
C19: 1uF; C0805
C99: 47uF; SMC_C
F1, F2, F3, F4, F5, F6, F7, F8, F9, F10, F11, F12, F13, F14, F15, F16: 3A; SH22,5
JP1, JP2: 1X03
JP3, JP4, JP5, JP6, JP7: 1X08
JP8, JP9: M16PTH; 1X16
JP10: 1X06
JP11, JP12: 1X02_LOCK
K1, K2, K3, K4, K5, K6, K7, K8, K9, K10, K11, K12, K13, K14, K15, K16: S202S01; S102S01
L1, L2, L3, L4, L5, L6, L7, L8, L9, L10, L11, L12, L13, L14, L15, L16: 300uH; ZD6-2W5
LED33: Red; LED-0603
LSP1, LSP2, LSP3, LSP4, LSP5, LSP6, LSP7, LSP8: MCS08
OK1: H11A1M; DIL06
Q1: BSS123; SOT23
R1, R2, R3, R4, R5, R6, R7, R8, R9, R10, R11, R12, R13, R14, R15, R16: 120R 2W; 0411/12
R17: 2k2; R0805
R18, R19, R20, R21, R22, R24, R25, R70, R71: 10k; R0805
R23: 1M; R0805
R55: 10k; M0805
R64: 330; 0805
R65: 10k; 0805
R66: 1k; R0805
R89, R99: 47k 1W; 0207/12
R91, R101, R111, R112, R113, R114, R115, R116, R117, R118, R119, R121, R131, R141, R161: 330R; M0805
S1: TACTILE-PTH
SV1, SV2, SV3, SV4, SV5, SV6, SV7, SV8: ML14
U$1: MIC9.7MM; MIC-9.7MM
U$2: OPA344; SOT23-5
X1: WAGO4-255-404-5; 255-404-5
X2, X3, X5, X6: WAGO8-255-408-5; 255-408-5
X10, X11, X12: 233-103
X13, X14, X15: 233-102

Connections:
3.3: JP10.2, Q1.1, R24.1
5V: R64.2, R65.2, X10.A1, X11.A1, X12.A1, X13.A1, X14.A1
A0: JP7.1, X10.A2
A1: JP7.2, X11.A2
A2: JP7.3, X12.A2
A3: JP7.4, R70.2, X13.A2
A4: JP7.5, R71.2, X14.A2
A5: JP7.6, R66.2, X15.A1
AC_NEUTRAL: R89.2, X1.B1, X1.B2, X2.B1, X2.B3, X2.B5, X2.B7, X3.B1, X3.B3, X3.B5, X3.B7, X5.B1, X5.B3, X5.B5, X5.B7, X6.B1, X6.B3, X6.B5, X6.B7
AC_PHASE: C1.1, C2.1, C3.1, C4.1, C5.1, C6.1, C7.1, C8.1, C9.1, C10.1, C11.1, C12.1, C13.1, C14.1, C15.1, C16.1, K1.2, K2.2, K3.2, K4.2, K5.2, K6.2, K7.2, K8.2, K9.2, K10.2, K11.2, K12.2, K13.2, K14.2, K15.2, K16.2, R99.2, X1.B3, X1.B4
D2: JP4.3, SV5.12
D3: JP4.4, OK1.5, R55.1, SV2.12
D4: C18.2, JP4.5, R23.1, SV3.5, U$2.1
D5: JP4.6, SV3.7
D6: JP4.7, SV2.8
D7: JP4.8, SV2.6
D8: JP3.1, SV2.4
D9: JP3.2, SV2.2
D10: JP3.3, SV2.1
D11: JP3.4, SV2.3
D12: JP3.5, SV2.5
D13: JP3.6, SV2.7
D14: JP5.1, R18.1, SV3.2
D15: JP5.2, Q1.3, R25.2, SV3.4
D16: JP1.2, JP5.3, SV3.6
D17: JP1.3, JP5.4, SV3.8
D18: JP5.5, SV4.7
D19: JP5.6, SV4.5
D22: JP9.16, SV4.2
D24: JP9.15, SV4.4
D26: JP9.14, SV4.6
D28: JP9.13, SV4.8
D30: JP9.12, SV5.1
D31: JP8.12, SV7.1
D32: JP9.11, SV5.2
D33: JP8.11, SV7.2
D34: JP9.10, SV5.3
D35: JP8.10, SV7.3
D36: JP9.9, SV5.4
D37: JP8.9, SV7.4
D38: JP9.8, SV5.5
D39: JP8.8, SV7.5
D40: JP9.7, SV5.6
D41: JP8.7, SV7.6
D42: JP9.6, SV5.7
D43: JP8.6, SV7.7
D44: JP9.5, SV5.8
D45: JP8.5, SV7.8
D46: JP9.4, SV6.1
D47: JP8.4, SV6.2
D48: JP9.3, SV6.3
D49: JP8.3, SV6.4
D50: JP9.2, SV6.5
D51: JP8.2, SV6.6
D52: JP9.1, SV6.7
D53: JP8.1, SV6.8
GND: C19.1, C99.-, JP1.1, JP2.1, JP3.7, JP10.4, JP10.5, JP11.1, JP11.2, K1.4, K2.4, K3.4, K4.4, K5.4, K6.4, K7.4, K8.4, K9.4, K10.4, K11.4, K12.4, K13.4, K14.4, K15.4, K16.4, LED33.C, LSP1.MP, LSP2.MP, LSP3.MP, LSP4.MP, LSP5.MP, LSP6.MP, LSP7.MP, LSP8.MP, OK1.4, R19.2, R22.1, R70.1, R71.1, S1.1, S1.2, SV2.13, SV3.13, SV4.13, SV5.13, SV6.13, SV7.13, U$1.1, U$2.2, X10.A3, X11.A3, X12.A3, X15.A2
INPUT1: R119.1, SV1.2
INPUT2: R112.1, SV1.1
INPUT3: R113.1, SV1.4
INPUT4: R114.1, SV1.3
INPUT5: R115.1, SV1.6
INPUT6: R116.1, SV1.5
INPUT7: R117.1, SV1.8
INPUT8: R118.1, SV1.7
INPUT9: R91.1, SV8.2
INPUT10: R101.1, SV8.1
INPUT11: R111.1, SV8.4
INPUT12: R121.1, SV8.3
INPUT13: R131.1, SV8.6
INPUT14: R141.1, SV8.5
INPUT15: 151.1, SV8.8
INPUT16: R161.1, SV8.7
LAMP1: F1.1, L1.2
LAMP2: F2.1, L2.2
LAMP3: F3.1, L3.2
LAMP4: F4.1, L4.2
LAMP5: F5.1, L5.2
LAMP6: F6.1, L6.2
LAMP7: F7.1, L7.2
LAMP8: F8.1, L8.2
LAMP9: F9.1, L9.2
LAMP10: F10.1, L10.2
LAMP11: F11.1, L11.2
LAMP12: F12.1, L12.2
LAMP13: F13.1, L13.2
LAMP14: F14.1, L14.2
LAMP15: F15.1, L15.2
LAMP16: F16.1, L16.2
unnamed: K2.1, L2.1, R2.2
unnamed: K1.1, L1.1, R1.1
unnamed: C1.2, R1.2
unnamed: C2.2, R2.1
unnamed: F4.2, X5.B8
unnamed: K3.1, L3.1, R3.2
unnamed: OK1.1, R99.1
unnamed: C3.2, R3.1
unnamed: F1.2, X5.B2
unnamed: F2.2, X5.B4
unnamed: C4.2, R4.1
unnamed: K4.1, L4.1, R4.2
unnamed: K5.1, L5.1, R5.2
unnamed: OK1.2, R89.1
unnamed: C5.2, R5.1
unnamed: F3.2, X5.B6
unnamed: K6.1, L6.1, R6.2
unnamed: C6.2, R6.1
unnamed: F5.2, X6.B2
unnamed: F8.2, X6.B8
unnamed: C7.2, R7.1
unnamed: K7.1, L7.1, R7.2
unnamed: K8.1, L8.1, R8.2
unnamed: C8.2, R8.1
unnamed: F7.2, X6.B6
unnamed: F6.2, X6.B4
unnamed: K2.3, R112.2
unnamed: K3.3, R113.2
unnamed: K4.3, R114.2
unnamed: K5.3, R115.2
unnamed: K6.3, R116.2
unnamed: K7.3, R117.2
unnamed: K8.3, R118.2
unnamed: K1.3, R119.2
unnamed: K10.3, R101.2
unnamed: K11.3, R111.2
unnamed: K12.3, R121.2
unnamed: K13.3, R131.2
unnamed: K14.3, R141.2
unnamed: 151.2, K15.3
unnamed: K16.3, R161.2
unnamed: K9.3, R91.2
unnamed: K9.1, L9.1, R9.1
unnamed: C9.2, R9.2
unnamed: K10.1, L10.1, R10.2
unnamed: C10.2, R10.1
unnamed: K11.1, L11.1, R11.2
unnamed: C11.2, R11.1
unnamed: C12.2, R12.1
unnamed: K12.1, L12.1, R12.2
unnamed: K13.1, L13.1, R13.2
unnamed: C13.2, R13.1
unnamed: K14.1, L14.1, R14.2
unnamed: C14.2, R14.1
unnamed: C15.2, R15.1
unnamed: K15.1, L15.1, R15.2
unnamed: K16.1, L16.1, R16.2
unnamed: C16.2, R16.1
unnamed: C17.1, R17.1, U$1.2
unnamed: C19.2, R21.1, R22.2, U$2.3
unnamed: C17.2, R20.2
unnamed: C18.1, R20.1, R23.2, U$2.4
unnamed: F12.2, X2.B8
unnamed: F9.2, X2.B2
unnamed: F10.2, X2.B4
unnamed: F11.2, X2.B6
unnamed: F13.2, X3.B2
unnamed: F16.2, X3.B8
unnamed: F15.2, X3.B6
unnamed: F14.2, X3.B4
unnamed: LED33.A, R64.1
RES: JP10.1, R65.1, S1.3, S1.4
RX0: JP4.1, SV3.1
RX3V3: JP2.2, R18.2, R19.1
SCL: JP5.8, SV4.1
SDA: JP5.7, SV4.3
TX1: JP4.2, SV3.3
TX3V3: JP2.3, Q1.2, R24.2
VCC: C99.+, JP10.3, JP12.1, JP12.2, R17.2, R21.2, R25.1, R55.2, R66.1, SV2.14, SV3.14, SV4.14, SV5.14, SV6.14, SV7.14, U$2.5

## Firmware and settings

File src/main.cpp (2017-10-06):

/*
  Blink
  Turns on an LED on for one second, then off for one second, repeatedly.
  Example uses a static library to show off generate_arduino_library().
 
  This example code is in the public domain.
 */
#if ARDUINO >= 100
    #include "Arduino.h"
#else
    #include "WProgram.h"
#endif


#include "dimmer.h"

/** SSR library **/
void setup() {
  // Start the UART
  Serial.begin(115200) ;
  Serial.setTimeout(-1);

  dimmer_init();
  //dimmer_set(PHASE_LEADING_EDGE, CHANNEL1, 200);
}

uint8_t readFromSerial() {
  while(Serial.available() < 1){
    ;
  }
  return Serial.read();
}

void loop() {
  uint8_t messageStart[2];
  uint8_t fire_type;
  uint8_t channel;
  uint8_t value;

  // Protocol: Start each message with 255 (= 0xFF)
  do {
    messageStart[0] = readFromSerial();
    messageStart[1] = readFromSerial();
  } while (messageStart[0] != 0xF6 && messageStart[1] != 0x6F);

  fire_type = readFromSerial();
  channel = readFromSerial();
  value = readFromSerial();

  dimmer_set(fire_type, channel, value);
}

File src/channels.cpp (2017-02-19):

//
// Created by floz on 18/02/17.
//

#include "channels.h"

#include <avr/io.h>

/**
 * output ports:
 *  - digital pin 4: PD4
 *  - digital pin 5: PD5
 *  - digital pin 6: PD6
 *  - digital pin 7: PD7
 *  - digital pin 8: PB0
 */
static t_channel channels[CHANNEL_COUNT] = {
        {
                .id = CHANNEL1,
                .enabled = false,
                .port = &PORTD,
                .ddr = &DDRD,
                .pin = PD4,
        },
        {
                .id = CHANNEL2,
                .enabled = false,
                .port = &PORTD,
                .ddr = &DDRD,
                .pin = PD5,
        },
        {
                .id = CHANNEL3,
                .enabled = false,
                .port = &PORTD,
                .ddr = &DDRD,
                .pin = PD6,
        },
        {
                .id = CHANNEL4,
                .enabled = false,
                .port = &PORTD,
                .ddr = &DDRD,
                .pin = PD7,
        },
        {
                .id = CHANNEL5,
                .enabled = false,
                .port = &PORTB,
                .ddr = &DDRB,
                .pin = PB0,
        }
};

void channels_init() {
  for (int i = 0; i < CHANNEL_COUNT; i++) {
    *channels[i].port &= ~(1<<channels[i].pin);
    *channels[i].ddr |= (1<<channels[i].pin);
  }
}

void channel_set_output(t_channel_nr channel, t_action action) {
  if (action == ON) {
    *channels[channel].port |= (1<<channels[channel].pin);
  } else {
    *channels[channel].port &= ~(1<<channels[channel].pin);
  }
}


// unused
void channel_enable(t_channel_nr chan_nr, t_action action, t_ticks ticks) {

  channels[chan_nr].enabled = false;
  channels[chan_nr].zc_action = action;
  channels[chan_nr].value = ticks;
  channels[chan_nr].enabled = true;
}

void channel_disable(t_channel_nr chan_nr) {
  channels[chan_nr].enabled = false;

  channel_set_output(chan_nr, OFF);
}

t_channel *channel_get(t_channel_nr chan_nr) {
  return &channels[chan_nr];
}

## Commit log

2017-01-18 Copy existing sources from local repo.
    [barbi_pozoriste_master_revb.brd, barbi_pozoriste_master_revb.sch, barbi_pozoriste_slave_revb.brd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]
2017-01-19 Adapt calibration offset to new resistor values.
2017-01-19 Adapt schematic and board layout according to new parts.
    [ssr.brd, ssr.sch]
2017-01-20 Export board layout files.
2017-02-19 hw: update PCB layout and outputs.
    [ssr.brd]
2017-02-19 fw: fix burst fire doing an additional cycle.
    [main.cpp]
2017-02-19 fw: correctly remove a channel from the event list.
    [main.cpp]
2017-02-23 add comments for driver.
